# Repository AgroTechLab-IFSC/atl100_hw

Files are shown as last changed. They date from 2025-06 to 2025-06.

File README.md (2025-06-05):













# ATL-100 (Hardware)

**ATL-100** is a multiparametric station developed by <a href="https://agrotechlab.lages.ifsc.edu.br">AgroTechLab (*Agribusiness Technology Development Laboratory*)</a> of <a href="https://www.ifsc.edu.br">IFSC (*Federal Institute of Santa Catarina*)</a>.

It can be used as meteorological station, agrometeorological station, hydrological station, aquaculture station, tide gauge station or fire monitoring station (forest or urban environment).

It is a PTH (*Plated-Through-Hole*) project based on the ESP32-S3 MCU that aims to be easy to produce and low cost, so it uses COTS (*Commercial Off-The-Shelf*) hardware.

## Features

The current version of the ATL-100 has the following features:

### Main Board

 - Power Supply (XL4005)
   - Input: 10V ~ 30V;
   - Current: 2.5A (typ.) / 5A (max. with heat sink);
   - Efficiency: 90%
   - Frequency: 300KHz
 - Power Supply Sensor
   - Voltage Divider (30V -> 3.33V);
 - MCU (ESP32-S3)
   - RISC 32 bits 240MHz dual-core;
   - 16Mb Flash;
   - 512Kb SRAM;
   - 16Kb SRAM in RTC;
   - 8Mb PSRAM;
   - 384Kb ROM;
 - RS-485 (HW-519)
   - TTL to RS-485 converter;
   - Modbus-RTU protocol;
   - Used to connect HaliSense TH-EC-PH-NPK soil sensor:
     - Soil temperature (-40 ~ 80 ℃);
     - Soil moisture (0 ~ 100 %);
     - Soil electroconductivity (0 ~ 20.000 us/cm);
     - Soil pH (3 ~ 9 pH);
     - Soil nitrogen, phosphorus, potassium (1 ~ 1999 mg/Kg or mg/L)
 - Windsock (voltage drop based);
 - Anemometer (pulse counter based);
 - Pluviometer (pulse counter based);
 - Air sensor (BME-280)
   - Air Temperature (-40 ~ 85 ℃);
   - Air Humidity (0 ~ 100 %);
   - Atmospheric Pressure (300 ~ 1100 hPa);

### ADC Board
 - ADC (ADS1115)
   - 16 bits resolution;
   - 4 channels (4mA ~ 20mA / 0V ~ 10V);

## 3D Images
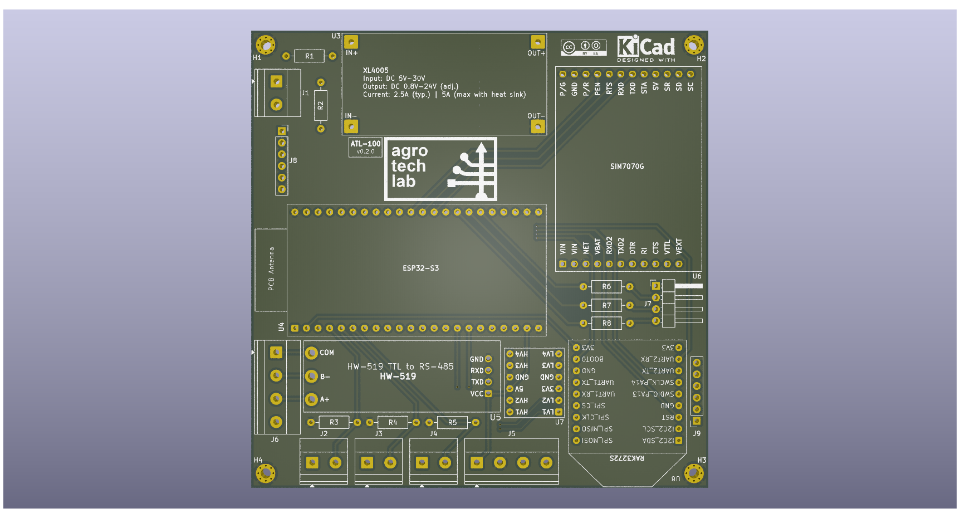
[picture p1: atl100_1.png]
3D image 1

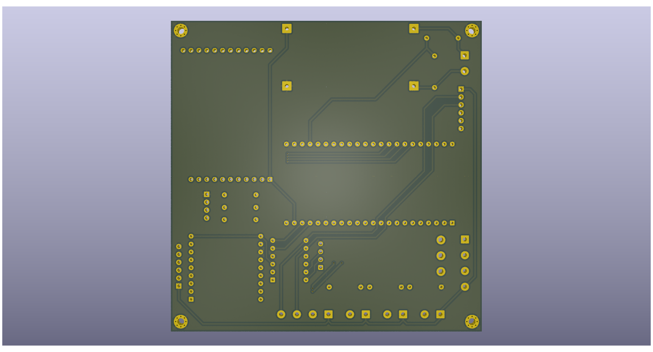
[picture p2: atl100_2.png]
3D image 2


<br><hr><p style="text-align: center;">All rights reserved. &copy; Since 2020.<br><b><a href="https://agrotechlab.lages.ifsc.edu.br/">AgroTechLab (<i>Agribusiness Technology Development Laboratory</i>)</a></b><br>
<b><a href="https://ifsc.edu.br/web/campus-lages">IFSC (<i>Federal Institute of Santa Catarina</i>) - Campus Lages</a></b><br>
225 Heitor Vila Lobos St., São Francisco<br>
Lages/SC - Brazil<br>
88506-400</p>

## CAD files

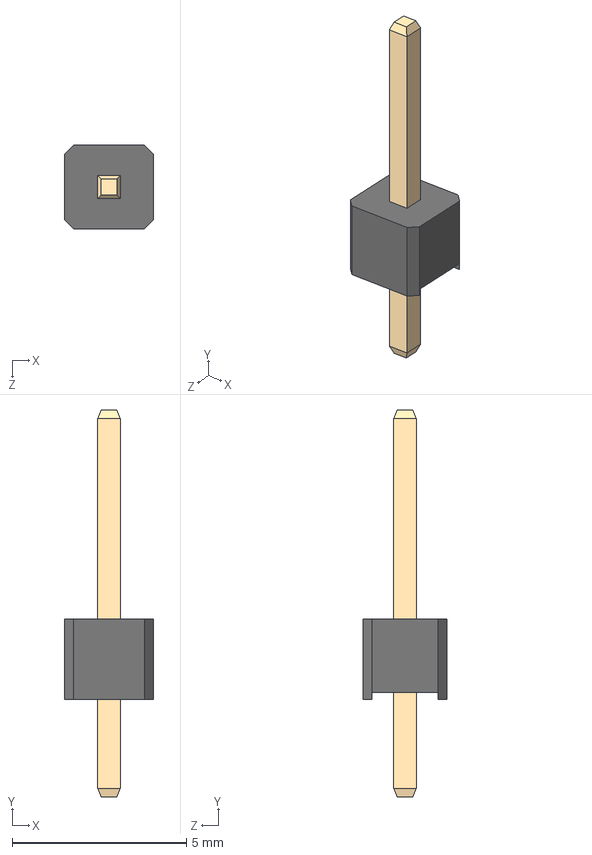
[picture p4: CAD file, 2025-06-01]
kicad_lib/3D/1x_Male_Pin_2.54_mm.STEP
2.54 x 11.1 x 2.40 mm

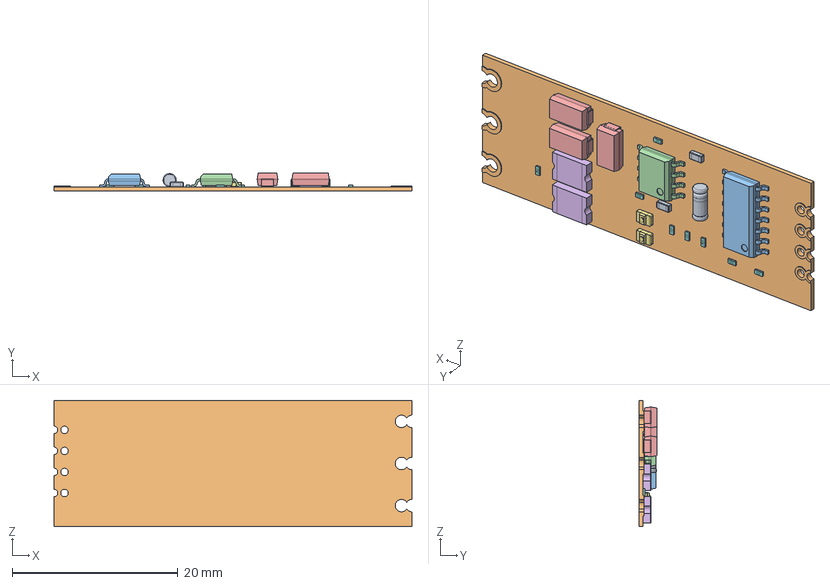
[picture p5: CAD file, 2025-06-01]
kicad_lib/3D/HW-519.step
43.2 x 2.15 x 15.2 mm
eMachineShop.1.1
eMachineShop.1.2
eMachineShop.1.3
eMachineShop.1.4
eMachineShop.1.5
eMachineShop.1.6
eMachineShop.1.7
eMachineShop.1.8
eMachineShop.1.9
eMachineShop.1.10
eMachineShop.1.11
eMachineShop.1.12
eMachineShop.1.13
eMachineShop.1.14
eMachineShop.1.15
eMachineShop.1.16
eMachineShop.1.17
eMachineShop.1.18
eMachineShop.1.19
eMachineShop.1.20
eMachineShop.1.21
eMachineShop.1.22
eMachineShop.1.23
eMachineShop.1.24
eMachineShop.1.25
eMachineShop.1.26
eMachineShop.1.27
eMachineShop.1.28
eMachineShop.1.29
eMachineShop.1.30
eMachineShop.1.31
eMachineShop.1.32
eMachineShop.1.33
eMachineShop.1.34
eMachineShop.2
eMachineShop.3
eMachineShop.4 x 3
eMachineShop.7 x 2
eMachineShop.9 x 2
eMachineShop.11 x 8
eMachineShop.19 x 2
eMachineShop.21.1
eMachineShop.21.2
eMachineShop.21.3
eMachineShop.21.4
eMachineShop.21.5
eMachineShop.21.6
eMachineShop.21.7
eMachineShop.21.8
eMachineShop.21.9
eMachineShop.21.10
eMachineShop.21.11
eMachineShop.21.12
eMachineShop.21.13
eMachineShop.21.14

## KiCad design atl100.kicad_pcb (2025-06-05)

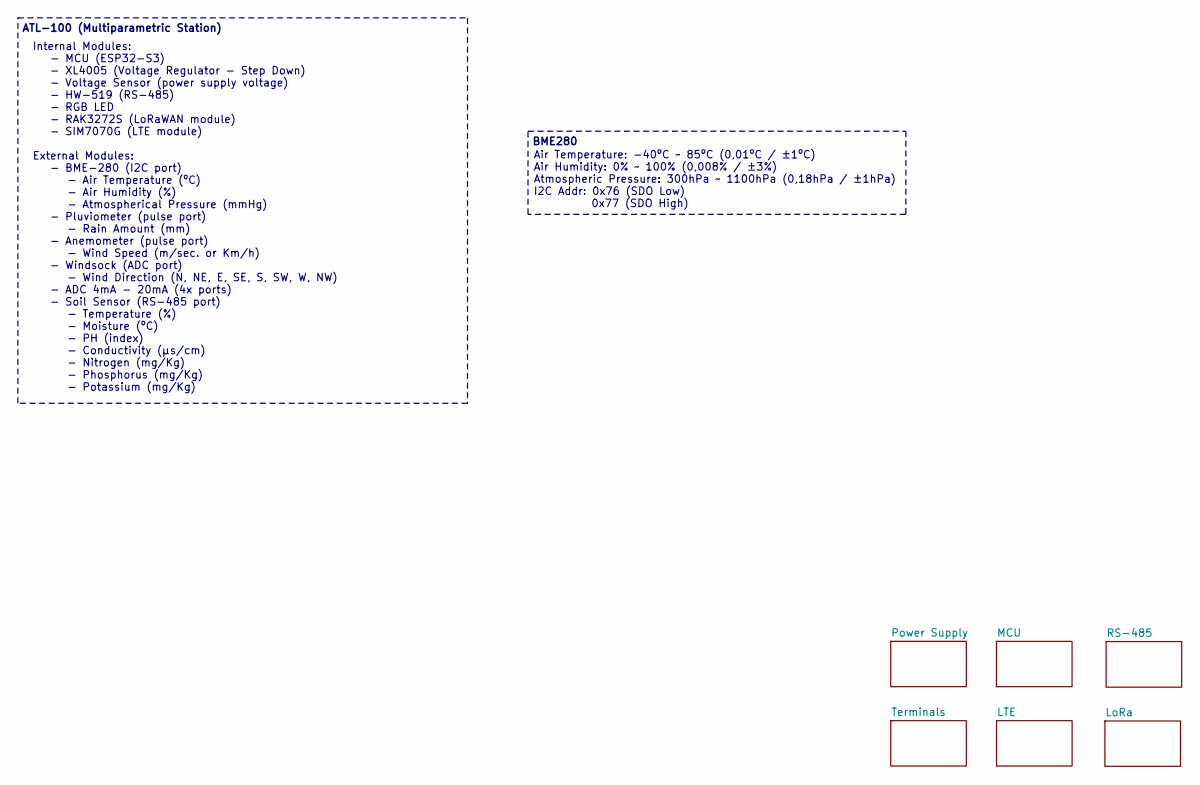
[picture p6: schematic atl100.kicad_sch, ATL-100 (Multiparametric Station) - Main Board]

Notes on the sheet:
BME280
Air Temperature: -40ºC ~ 85ºC (0,01ºC / ±1ºC) Air Humidity: 0% ~ 100% (0,008% / ±3%) Atmospheric Pressure: 300hPa ~ 1100hPa (0,18hPa / ±1hPa) I2C Addr: 0x76 (SDO Low) 0x77 (SDO High)
Internal Modules: - MCU (ESP32-S3) - XL4005 (Voltage Regulator - Step Down) - Voltage Sensor (power supply voltage) - HW-519 (RS-485) - RGB LED - RAK3272S (LoRaWAN module) - SIM7070G (LTE module) External Modules: - BME-280 (I2C port) - Air Temperature (ºC) - Air Humidity (%) - Atmospherical Pressu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
ATL-100 (Multiparametric Station)

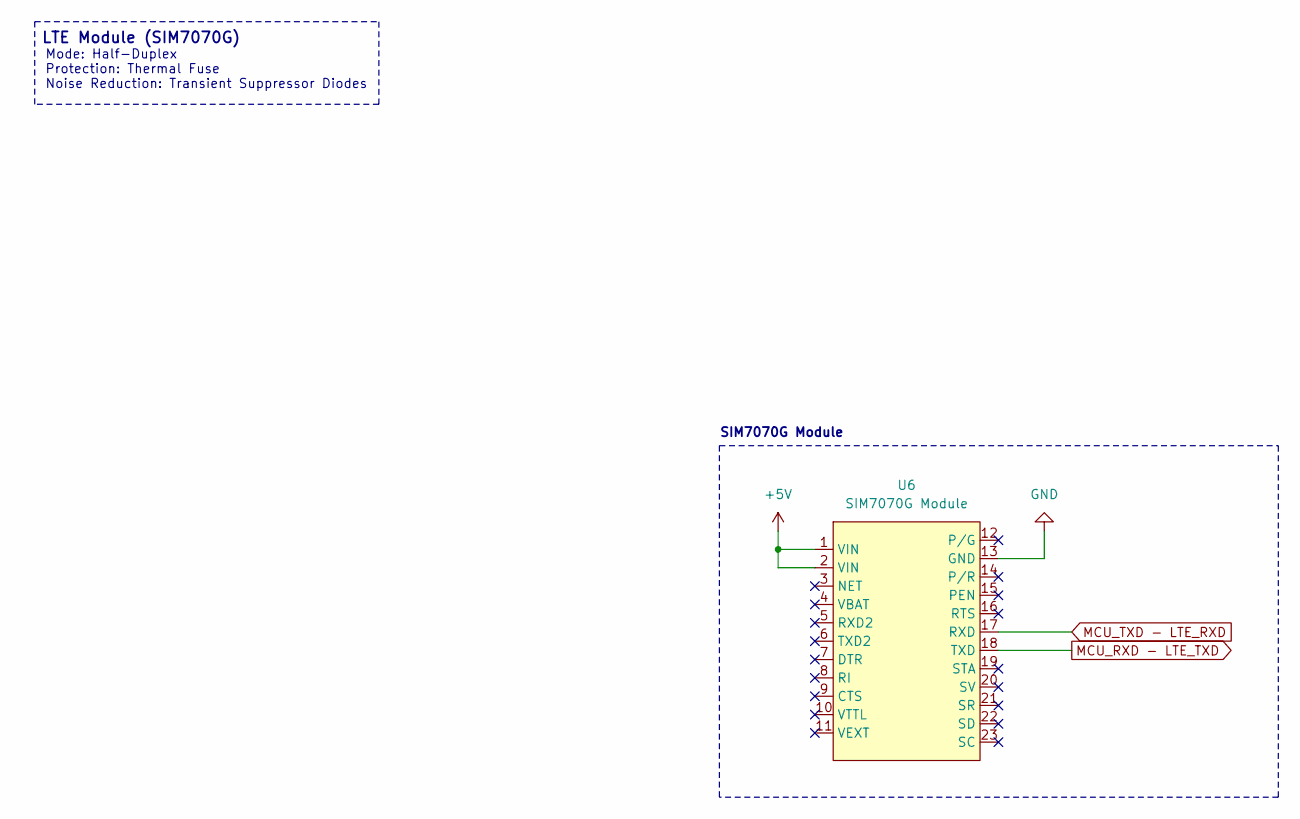
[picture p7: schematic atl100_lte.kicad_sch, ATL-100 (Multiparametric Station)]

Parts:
U6: SIM7070G Module; Part Number OEM

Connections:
+5V: U6.1 (VIN), U6.2 (VIN); also elsewhere on the board
GND: U6.12 (P/G), U6.13 (GND); also elsewhere on the board
LTE_PEN: U6.15 (PEN); also elsewhere on the board

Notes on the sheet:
LTE Module (SIM7070G)
SIM7070G Module
Mode: Half-Duplex Protection: Thermal Fuse Noise Reduction: Transient Suppressor Diodes

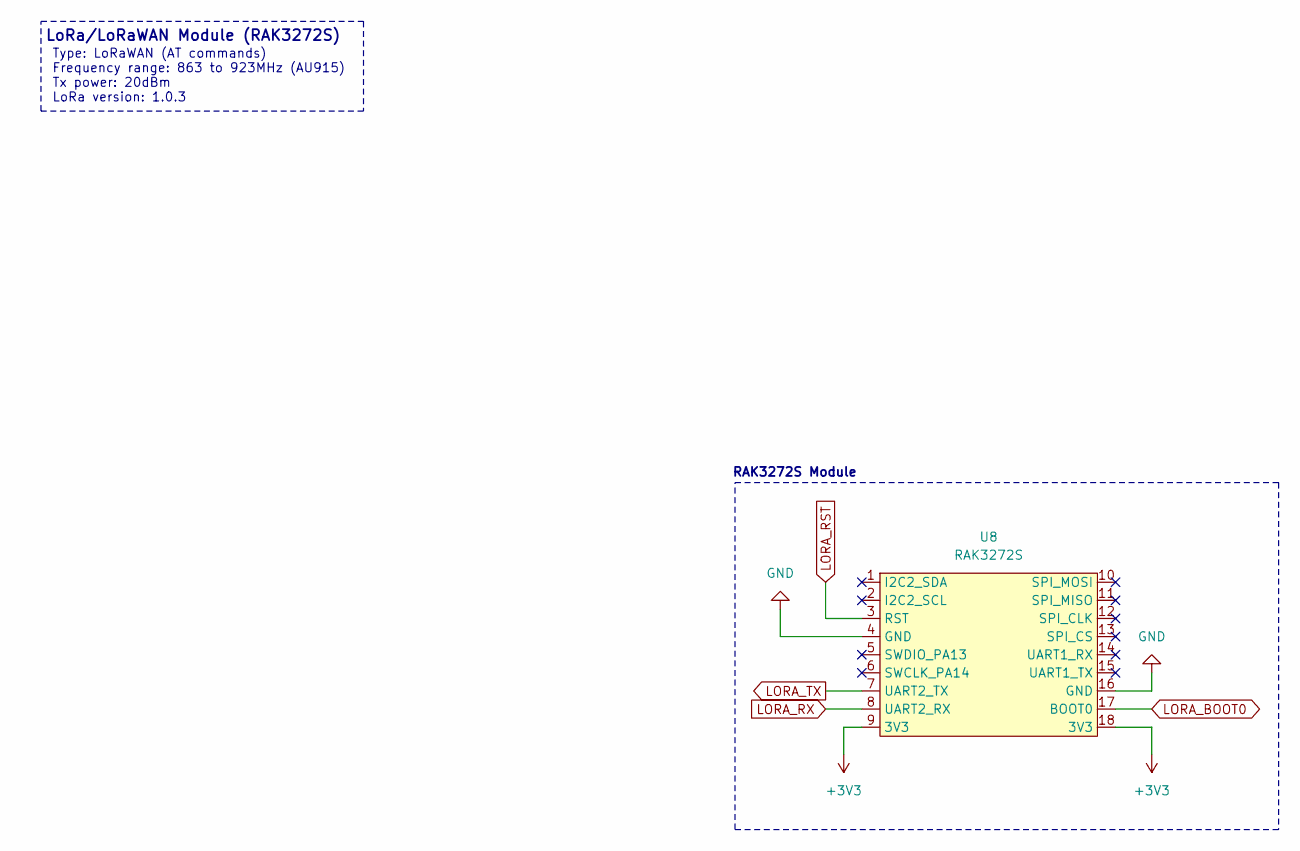
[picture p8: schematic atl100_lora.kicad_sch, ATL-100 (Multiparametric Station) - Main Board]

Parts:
U8: RAK3272S

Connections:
+3V3: U8.9 (3V3), U8.18 (3V3); also elsewhere on the board
GND: U8.4 (GND), U8.16 (GND); also elsewhere on the board
LORA_BOOT0: U8.17 (BOOT0); also elsewhere on the board
LORA_RST: U8.3 (RST); also elsewhere on the board
LORA_RX: U8.8 (UART2_RX); also elsewhere on the board
LORA_TX: U8.7 (UART2_TX); also elsewhere on the board

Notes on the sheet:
LoRa/LoRaWAN Module (RAK3272S)
Type: LoRaWAN (AT commands) Frequency range: 863 to 923MHz (AU915) Tx power: 20dBm LoRa version: 1.0.3
RAK3272S Module

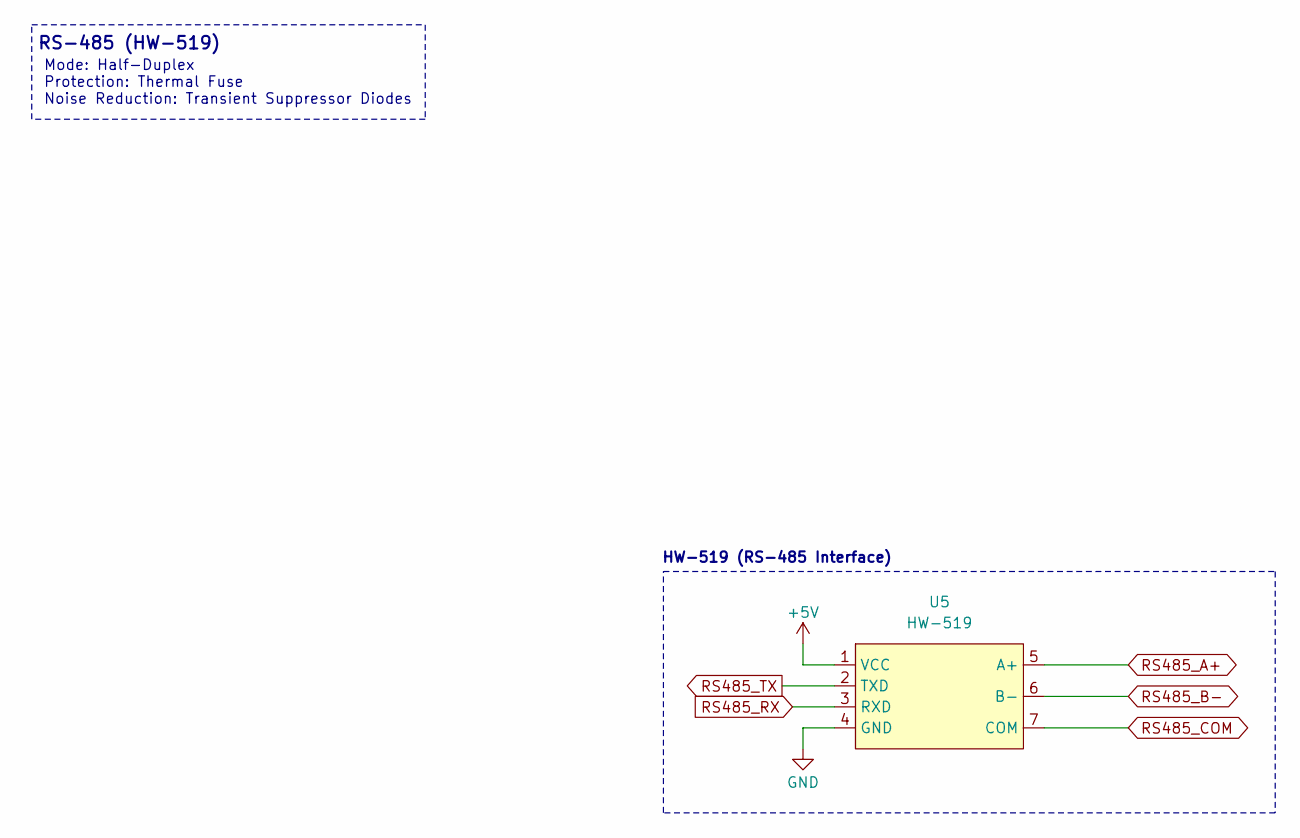
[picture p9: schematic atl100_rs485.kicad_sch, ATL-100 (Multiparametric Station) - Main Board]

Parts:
U5: HW-519

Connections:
+5V: U5.1 (VCC); also elsewhere on the board
GND: U5.4 (GND); also elsewhere on the board
RS485_A+: U5.5 (A+); also elsewhere on the board
RS485_B-: U5.6 (B-); also elsewhere on the board
RS485_COM: U5.7 (COM); also elsewhere on the board
RS485_RX: U5.3 (RXD); also elsewhere on the board
RS485_TX: U5.2 (TXD); also elsewhere on the board

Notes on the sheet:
RS-485 (HW-519)
Mode: Half-Duplex Protection: Thermal Fuse Noise Reduction: Transient Suppressor Diodes
HW-519 (RS-485 Interface)

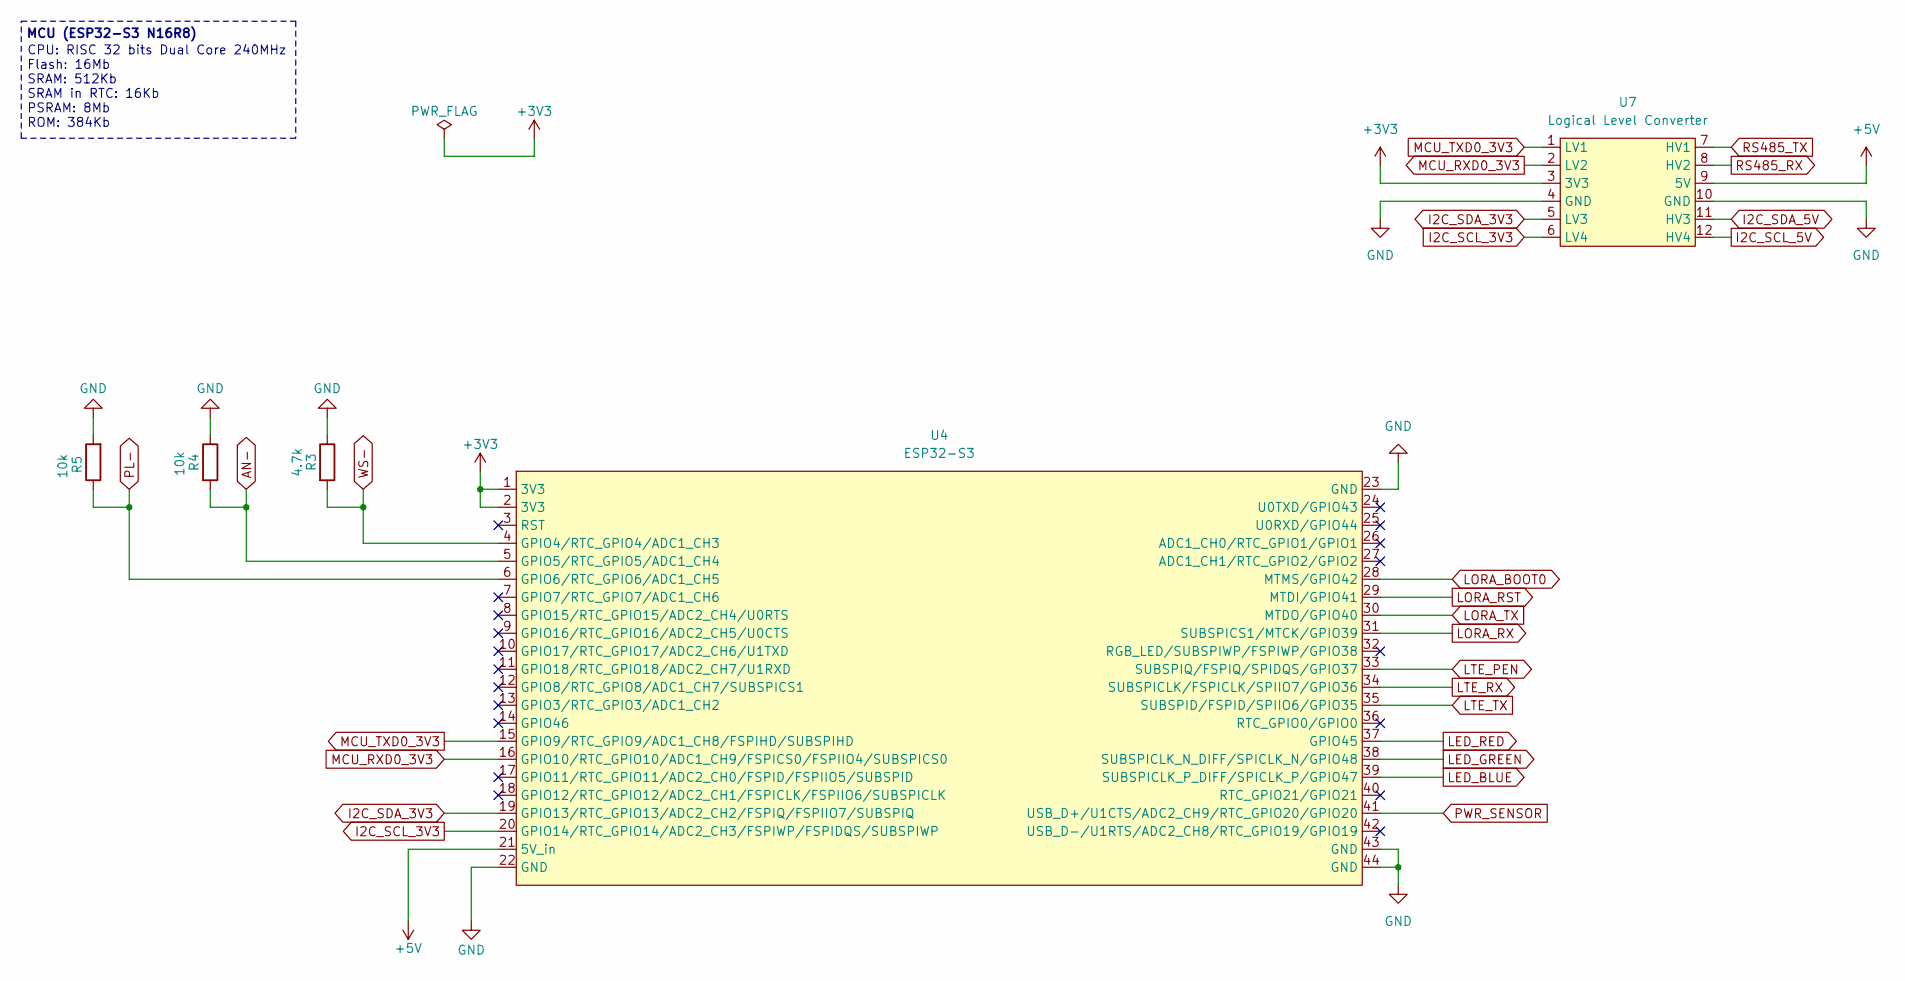
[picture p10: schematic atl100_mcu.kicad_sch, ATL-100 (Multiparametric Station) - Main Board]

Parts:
R3: 4.7k; R_Axial_DIN0207_L6.3mm_D2.5mm_P10.16mm_Horizontal; Part Number Std
R4, R5: 10k; R_Axial_DIN0207_L6.3mm_D2.5mm_P10.16mm_Horizontal; Part Number Std
U4: ESP32-S3; ESP32-S3 N16R8
U7: Logical Level Converter

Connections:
+3V3: U4.1 (3V3), U4.2 (3V3), U7.3 (3V3); also elsewhere on the board
+5V: U4.21 (5V_in), U7.9 (5V); also elsewhere on the board
AN-: R4.2, U4.5 (GPIO5/RTC_GPIO5/ADC1_CH4); also elsewhere on the board
GND: R3.1, R4.1, R5.2, U4.22 (GND), U4.23 (GND), U4.43 (GND), U4.44 (GND), U7.4 (GND), U7.10 (GND); also elsewhere on the board
I2C_SCL_3V3: U4.20 (GPIO14/RTC_GPIO14/ADC2_CH3/FSPIWP/FSPID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), U7.6 (LV4)
I2C_SCL_5V: U7.12 (HV4); also elsewhere on the board
I2C_SDA_3V3: U4.19 (GPIO13/RTC_GPIO13/ADC2_CH2/FSPIQ/FSPIIO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), U7.5 (LV3)
I2C_SDA_5V: U7.11 (HV3); also elsewhere on the board
LED_BLUE: U4.39 (SUBSPICLK_P_DIFF/SPICLK_P/GPIO47); also elsewhere on the board
LED_GREEN: U4.38 (SUBSPICLK_N_DIFF/SPICLK_N/GPIO48); also elsewhere on the board
LED_RED: U4.37 (GPIO45); also elsewhere on the board
LORA_BOOT0: U4.28 (MTMS/GPIO42); also elsewhere on the board
LORA_RST: U4.29 (MTDI/GPIO41); also elsewhere on the board
LORA_RX: U4.31 (SUBSPICS1/MTCK/GPIO39); also elsewhere on the board
LORA_TX: U4.30 (MTDO/GPIO40); also elsewhere on the board
LTE_PEN: U4.33 (SUBSPIQ/FSPIQ/SPIDQS/GPIO37); also elsewhere on the board
MCU_RXD0_3V3: U4.16 (GPIO10/RTC_GPIO10/ADC1_CH9/FSPICS0/FSPI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), U7.2 (LV2)
MCU_TXD0_3V3: U4.15 (GPIO9/RTC_GPIO9/ADC1_CH8/FSPIHD/SUBSPIHD), U7.1 (LV1)
PL-: R5.1, U4.6 (GPIO6/RTC_GPIO6/ADC1_CH5); also elsewhere on the board
PWR_SENSOR: U4.41 (USB_D+/U1CTS/ADC2_CH9/RTC_GPIO20/GPIO20); also elsewhere on the board
RS485_RX: U7.8 (HV2); also elsewhere on the board
RS485_TX: U7.7 (HV1); also elsewhere on the board
WS-: R3.2, U4.4 (GPIO4/RTC_GPIO4/ADC1_CH3); also elsewhere on the board

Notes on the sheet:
CPU: RISC 32 bits Dual Core 240MHz Flash: 16Mb SRAM: 512Kb SRAM in RTC: 16Kb PSRAM: 8Mb ROM: 384Kb
MCU (ESP32-S3 N16R8)

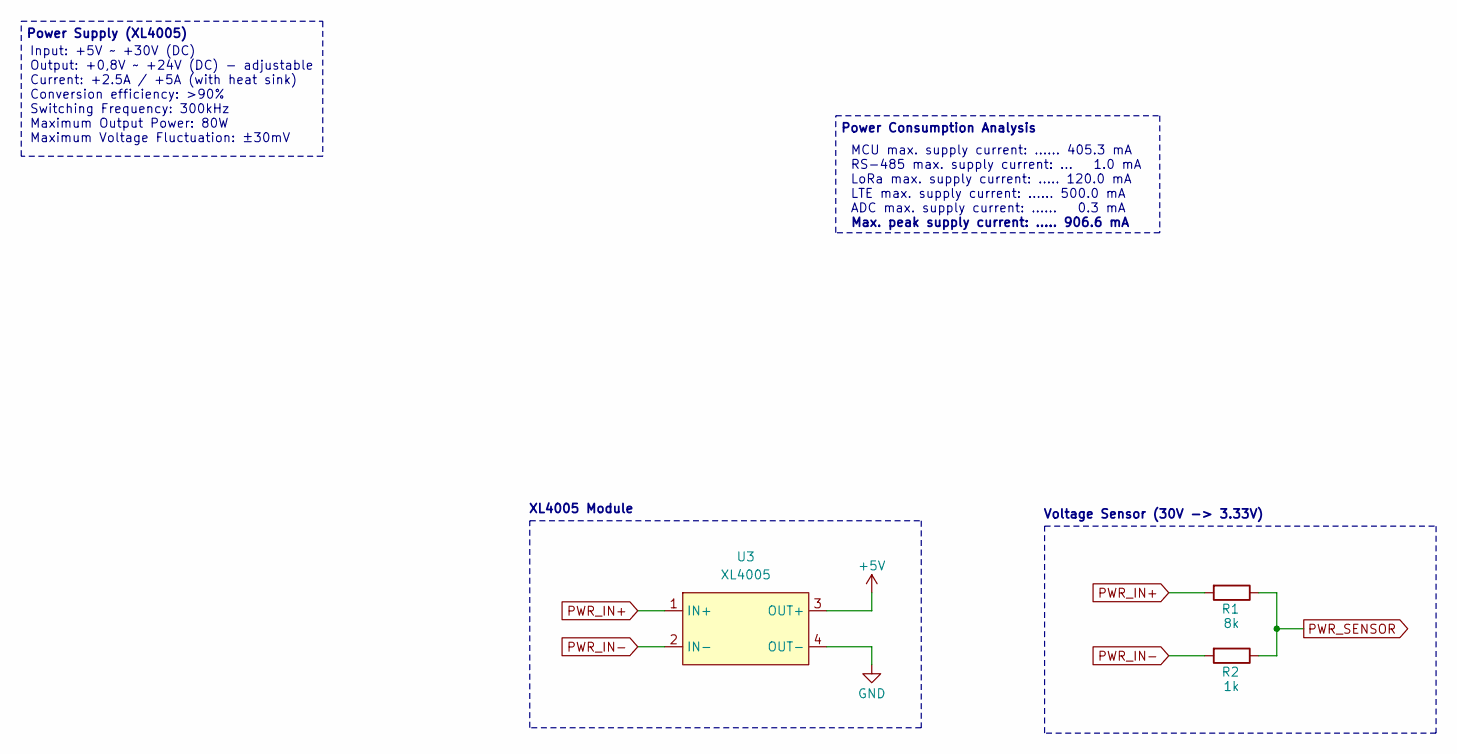
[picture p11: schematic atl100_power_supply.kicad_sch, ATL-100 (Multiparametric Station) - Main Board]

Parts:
R1: 8k; R_Axial_DIN0207_L6.3mm_D2.5mm_P10.16mm_Horizontal; Part Number Std
R2: 1k; R_Axial_DIN0207_L6.3mm_D2.5mm_P10.16mm_Horizontal; Part Number Std
U3: XL4005; Part Number Std

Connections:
+5V: U3.3 (OUT+); also elsewhere on the board
GND: U3.4 (OUT-); also elsewhere on the board
PWR_IN+: R1.2, U3.1 (IN+); also elsewhere on the board
PWR_IN-: R2.2, U3.2 (IN-); also elsewhere on the board
PWR_SENSOR: R1.1, R2.1; also elsewhere on the board

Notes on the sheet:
Voltage Sensor (30V -> 3.33V)
XL4005 Module
Max. peak supply current: ..... 906.6 mA
MCU max. supply current: ...... 405.3 mA RS-485 max. supply current: ... 1.0 mA LoRa max. supply current: ..... 120.0 mA LTE max. supply current: ...... 500.0 mA ADC max. supply current: ...... 0.3 mA
Input: +5V ~ +30V (DC) Output: +0,8V ~ +24V (DC) - adjustable Current: +2.5A / +5A (with heat sink) Conversion efficiency: >90% Switching Frequency: 300kHz Maximum Output Power: 80W Maximum Voltage Fluctuation: ±30mV
Power Consumption Analysis
Power Supply (XL4005)

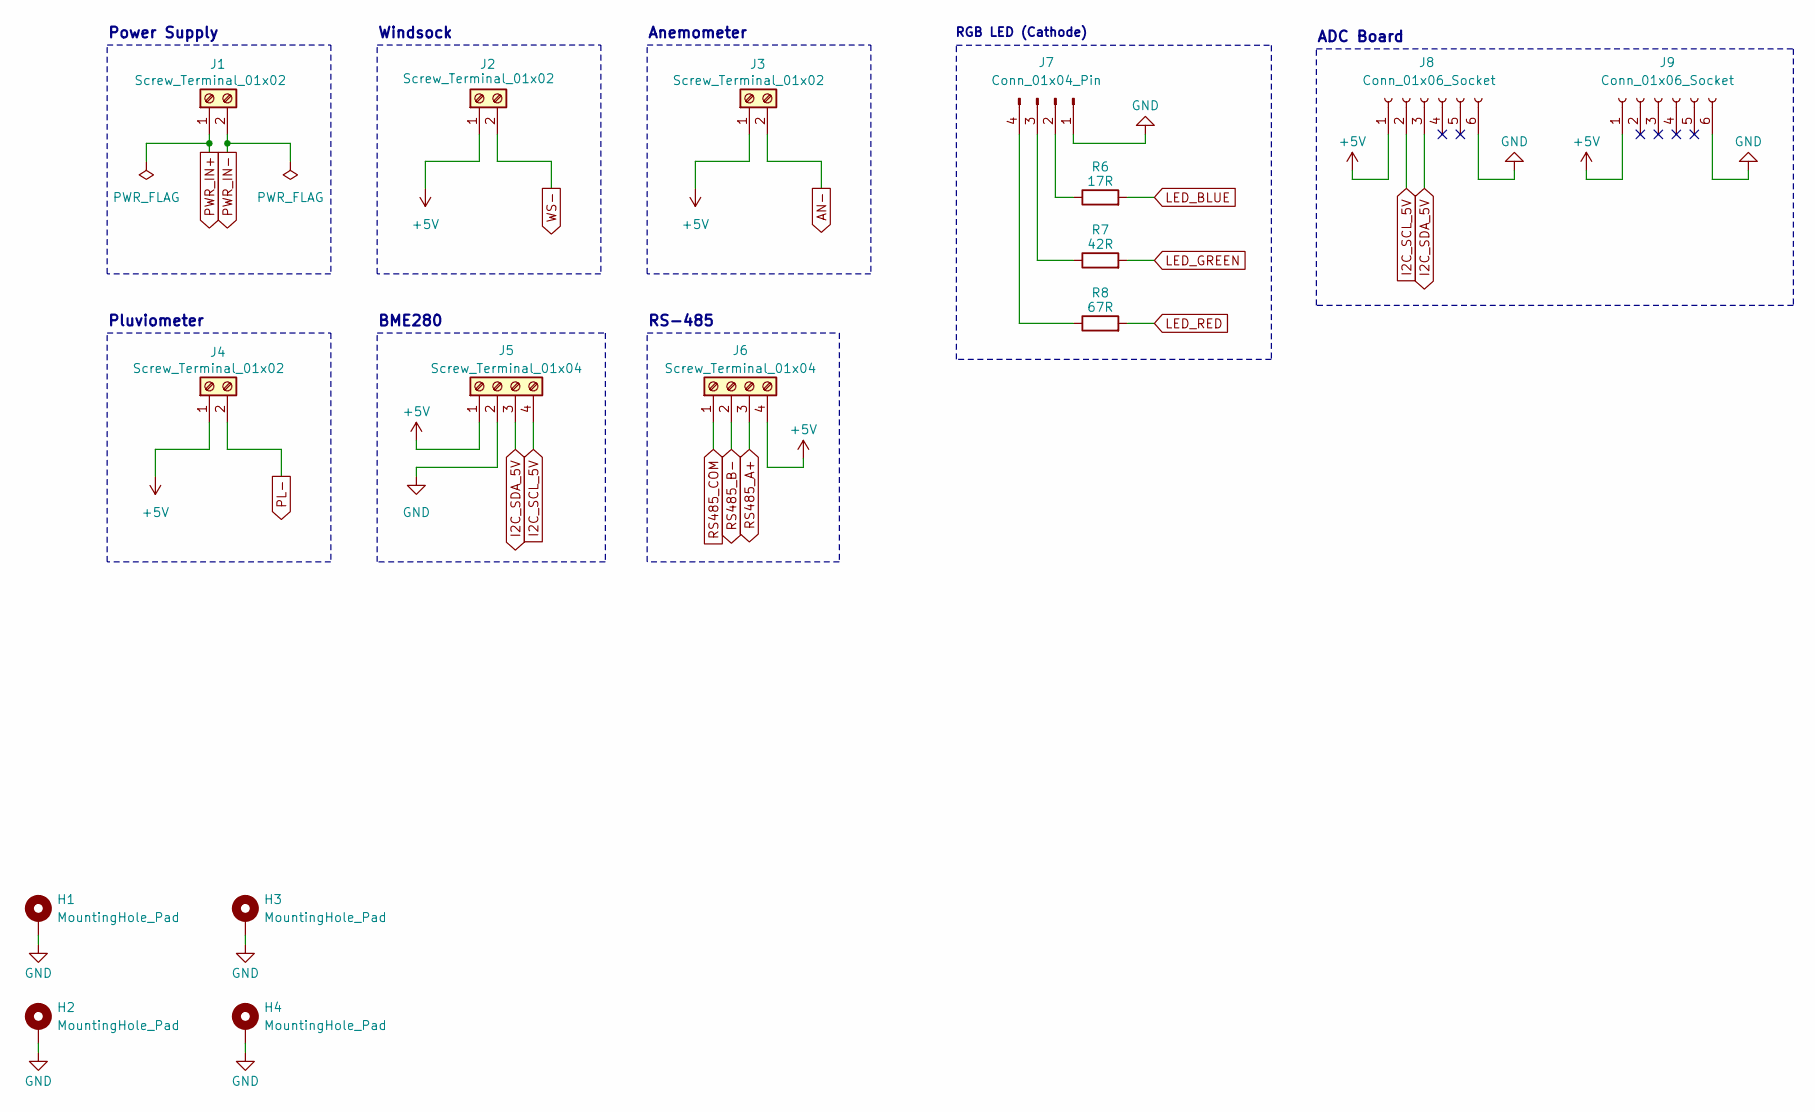
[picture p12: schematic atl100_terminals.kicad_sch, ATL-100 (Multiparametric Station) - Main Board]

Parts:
H1, H2, H3, H4: MountingHole_Pad; MountingHole_2.2mm_M2_Pad_Via
J1, J2, J3, J4: Screw_Terminal_01x02; TerminalBlock_Phoenix_MKDS-1,5-2-5.08_1x02_P5.08mm_Horizont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; Part Number Std
J5, J6: Screw_Terminal_01x04; TerminalBlock_Phoenix_MKDS-1,5-4-5.08_1x04_P5.08mm_Horizont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; Part Number Std
J7: Conn_01x04_Pin; PinHeader_1x04_P2.54mm_Horizontal
J8, J9: Conn_01x06_Socket; PinSocket_1x06_P2.54mm_Vertical
R6: 17R; R_Axial_DIN0207_L6.3mm_D2.5mm_P10.16mm_Horizontal; Part Number Std
R7: 42R; R_Axial_DIN0207_L6.3mm_D2.5mm_P10.16mm_Horizontal; Part Number Std
R8: 67R; R_Axial_DIN0207_L6.3mm_D2.5mm_P10.16mm_Horizontal; Part Number Std

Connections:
+5V: J2.1, J3.1, J4.1, J5.1, J6.4, J8.1, J9.1; also elsewhere on the board
AN-: J3.2; also elsewhere on the board
GND: H1.1, H2.1, H3.1, H4.1, J5.2, J7.1, J8.6, J9.6; also elsewhere on the board
I2C_SCL_5V: J5.4, J8.2; also elsewhere on the board
I2C_SDA_5V: J5.3, J8.3; also elsewhere on the board
LED_BLUE: R6.2; also elsewhere on the board
LED_GREEN: R7.2; also elsewhere on the board
LED_RED: R8.2; also elsewhere on the board
unnamed: J7.2, R6.1
unnamed: J7.3, R7.1
unnamed: J7.4, R8.1
PL-: J4.2; also elsewhere on the board
PWR_IN+: J1.1; also elsewhere on the board
PWR_IN-: J1.2; also elsewhere on the board
RS485_A+: J6.3; also elsewhere on the board
RS485_B-: J6.2; also elsewhere on the board
RS485_COM: J6.1; also elsewhere on the board
WS-: J2.2; also elsewhere on the board

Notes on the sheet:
Anemometer
Windsock
Pluviometer
ADC Board
Power Supply
BME280
RS-485
RGB LED (Cathode)

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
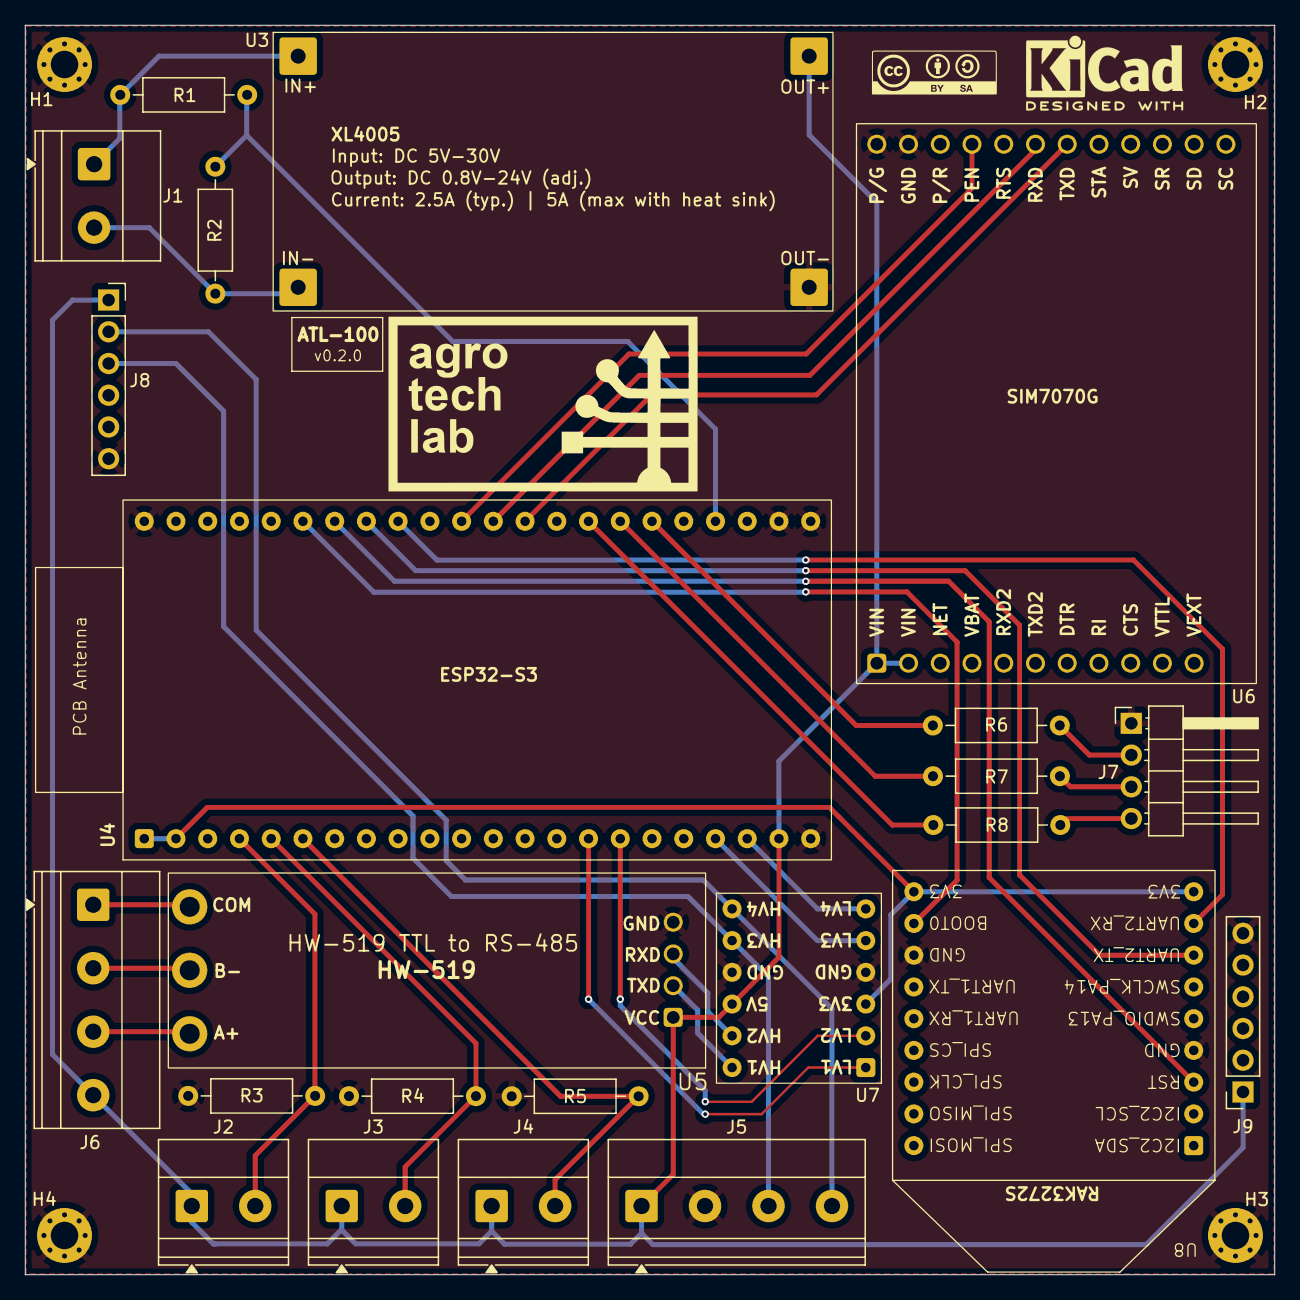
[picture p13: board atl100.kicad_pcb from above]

Board: 2 copper layers, 100.0 x 100.0 mm, 30 parts (0 on the bottom side), 33 nets.

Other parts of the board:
agrotechlab_logo: Logo AgroTechLab
cc_by_sa_logo: Logo CC-BY-SA
kicad_logo: KiCad-Logo2_5mm_SilkScreen

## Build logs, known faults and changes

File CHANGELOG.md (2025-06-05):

# Changelog

## <b>Version 0.2.0 (06/06/2025):</b>
   - Adjusted PCB size to 100mm x 100mm (production cost reduction);
   - Removed ADC and created a separate <b>Main Board</b> and <b>ADC Board</b> projects;

## <b>Version 0.1.0 (14/01/2025):</b>
   - THT project with:
      - Power Supply (XL-4005);
	  - MCU (ESP32-S3);
	  - RS-485 (HW-519);
	  - Communication (SIM-7070G);
	  - Digital Inputs;
	  - Analog Inputs (ADS-1115);

<br><hr><p style="text-align: center;"><b><a href="https://agrotechlab.lages.ifsc.edu.br/">AgroTechLab (<i>Laboratório de Desenvolvimento de Tecnologias para o Agronegócio</i>)</a></b><br>
<b><a href="https://ifsc.edu.br/web/campus-lages">IFSC (<i>Instituto Federal de Santa Catarina</i>) - Câmpus Lages</a></b><br>
Rua Heitor Vila Lobos, 225 - São Francisco<br>
Lages/SC - Brazil<br>
CEP: 88.506-400</p>

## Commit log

2024-07-01 feat: RS-485 #6
    [analog_inputs.kicad_sch, atl100.kicad_pcb, atl100.kicad_sch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]
2024-09-06 feat: Schematic updated (v0.1.0)
    [analog_inputs.kicad_sch, atl100_mcu.kicad_sch, atl100_modules.kicad_sch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]
2024-10-28 feat: Version 1.0.0
    [ai.kicad_sch, atl100_ai.kicad_sch, atl100_lte.kicad_sch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]
2024-10-30 feat: Updated pins to RS-485 UART
    [atl100_ai.kicad_sch, atl100_lte.kicad_sch, atl100_mcu.kicad_sch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]
2025-01-14 feat: Released v0.1.0 of THT project
    [atl100_ai.kicad_sch, atl100_lte.kicad_sch, atl100_mcu.kicad_sch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]
2025-06-01 build: Project refactory
    [1x_Male_Pin_2.54_mm.STEP, HW-519.step, ai.kicad_sch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]
2025-06-02 feat: Main board schematic updated
    [atl100.kicad_sch, atl100_adc_board.kicad_pcb, atl100_adc_board.kicad_sch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]
2025-06-05 feat: Updated to v0.2.0
    [atl100.kicad_pcb, atl100.kicad_sch, atl100_lora.kicad_sch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]

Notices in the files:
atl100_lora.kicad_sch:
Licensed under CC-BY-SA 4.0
